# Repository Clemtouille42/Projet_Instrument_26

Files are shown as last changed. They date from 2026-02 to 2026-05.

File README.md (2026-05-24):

#  Projet Instrument : Harpe Sans Contact

##  Présentation générale
Ce projet consiste à concevoir et réaliser une harpe électronique sans cordes physiques, dans laquelle les cordes traditionnelles sont remplacées par des faisceaux de détection. Lorsqu'un utilisateur est détecté par le capteur, la harpe analyse la position et la hauteur de la main pour émettre une note de musique spécifique. Ce système reproduit le principe de jeu d'une harpe classique tout en exploitant des technologies modernes de détection et de traitement du signal.

##  Objectifs du projet
* Mettre en œuvre une détection spatiale précise à l'aide d'un capteur multizone.
* Concevoir une carte électronique sur mesure intégrant la gestion d'alimentation et le traitement.
* Traiter les données de distance en temps réel pour les transformer en notes musicales.
* Restituer un signal sonore propre correspondant à la note calculée.

---

##  Architecture du système

Notre architecture repose sur trois grands piliers matériels, de la détection à la restitution sonore, en passant par une gestion rigoureuse de l'énergie.

### 1. Détection des mouvements
* **Capteur Time-of-Flight (ToF) :** VL53L8CX, utilisé pour déterminer avec précision la distance et la position de la main dans l'espace.
* **Adaptation et Communication :** Communication via le bus I2C avec des résistances de Pull-up (4.7 kΩ) sur les lignes SDA/SCL. Un adaptateur de niveaux est prévu pour assurer la compatibilité des signaux entre le capteur et le microcontrôleur.
* **Connectique :** Connecteurs dédiés pour lier physiquement le module capteur à la carte de traitement principale.

### 2. Traitement et Gestion de l'Énergie
* **Microcontrôleur :** STM32G431KB. Il est le cerveau du système : il reçoit les données de position du capteur via I2C et les convertit mathématiquement en notes (ex: mapping de plages de distances vers DO, RE, MI...).
* **Gestion de l'alimentation :** * **Alimentation directe en 5V** via le connecteur USB-C.
  * **Résistances CC (5.1 kΩ) :** Tirées vers la masse (GND) sur les broches CC1 et CC2 pour la négociation de puissance et assurer que le système reçoit bien ses 5V.
  * **LDO (Régulateur de tension) :** Abaisse le 5V en une tension stable de 3.3V, indispensable pour alimenter le microcontrôleur et le capteur ToF.
  * **Filtrage et découplage :** Utilisation de billes de ferrite et de condensateurs de découplage pour garantir une tension propre, sans parasites, afin de ne pas perturber les communications I2C et les traitements internes.

### 3. Restitution du signal
* **Isolation :** Optocoupleur pour garantir l'isolation électrique, protéger le microcontrôleur et éliminer les boucles de masse.
* **Audio :** Le signal est traité par un amplificateur avant d'être envoyé au mini haut-parleur pour la vibration sonore finale.
* **Interface externe :** Prise / Câble MIDI permettant une sortie numérique vers d'autres instruments ou un ordinateur.

---

##  Logiciel Embarqué (Work In Progress)

Le firmware (dossier `/CODE`) est actuellement en cours de développement et de débogage.

* **Communication :** Interfaçage I2C en cours d'implémentation pour récupérer la matrice de données du VL53L8CX.
* **Algorithme prévu :** Découpage du champ de vision du capteur en plusieurs zones virtuelles. Chaque zone correspond à une "corde". La distance mesurée dans une zone détermine la hauteur de la note (Grave/Aiguë) tandis que la zone elle-même détermine la note de la gamme.

---

##  Structure du dépôt

L'arborescence du projet est organisée de la manière suivante :

* 📁 **`Armature harpe/`** : Fichiers liés à la structure mécanique de la harpe (bois, impression 3D).
* 📁 **`CODE/`** : Code source C pour le microcontrôleur STM32 (En cours de développement).
* 📁 **`Commandes/`** : Contien les resource concernant la conception du pcb.
* 📁 **`Composants/`** : Regroupe toutes les ressources matérielles brutes (Datasheets des composants, empreintes spécifiques, nomenclature complète `composants.xlsx`).
* 📁 **`KiCad Harpe/`** : Projet KiCad complet incluant les schémas électroniques et le routage du PCB de notre carte sur mesure.
Pour plus de détaille lire les readme des sous parties.
---

##  L'Équipe

Projet réalisé dans le cadre de notre 1ère année de cycle ingénieur (ENSEA) par :

* **Clément SERVAES** - Le Grand Manitou
* **Damien GANTCHEV** - Le Grand Vizir
* **Serge AROU** - Le Grand Chanteur
* **Maxime LEBRUN** - Le Grand Brun

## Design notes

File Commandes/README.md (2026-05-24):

# Conception du PCB et choix des composants

Ce readme va aborder la partie conception du pcb et choix des composants en détail. Je vais le faire pour chaque partie que l'on peut voir sur le schematics, donc je vous invite à le regarder.

---

## Régulateur / alimentation

Cette partie est composée de deux régulateurs de tension en série qui régulent successivement le 5V puis le 3.3V pour délivrer du 1.8V et 3.3V. La source d'alimentation principale pour la carte est le 5V de l'USB.

### Choix des composants

* **Le BU33SD5WG-TR :** C'est un régulateur qui sort du 3.3V. Celui-ci sert à alimenter les composants fonctionnant en 3.3V avec le 5V de l'usb. C'est un composant plutôt standard pour ce genre de tâche.

* **AP2112K-1.8 :** C'est aussi un régulateur, sauf que celui-ci sort du 1.8V. Le choix de ce composant est plus stratégique car il sort sur IOvdd qui est extrêmement important pour le lidar (qui est alimenté en 3.3v et 1.8v). J'ai choisi ce composant car il ne laisse pas passer de bruit, possède un bon taux de réjection et le courant fourni correspond à la consommation.

---

## Conception
La principale contrainte de cette architecture réside dans l'alimentation en 1,8 V des lignes d'entrées/sorties (E/S) du microcontrôleur STM32. L'objectif initial était d'intégrer des adaptateurs de niveau logique (*level shifters*) afin d'éviter une sous-alimentation du STM32 mais cette option a été écarté pour simplifier la conception du pcb (réduire le nombre de composants). 

Cette configuration a imposé des contraintes d'interfaçage, la plupart des autres composants du PCB utilisant une tension IOVDD standard à 3,3 V. Cela a généré des conflits de compatibilité, notamment :
* L'interface de programmation ST-Link, qui opère nativement avec des niveaux logiques de 3,3 V.
* L'interface de débogage SWD, qui s'est retrouvée privée de sa tension de référence IOVDD.
---

## Voie d'amélioration

Les régulateurs ont une pin on/off (enable) qui permet de les désactiver ou activer. Sauf que j'ai routé la pin vers le STM32 afin de pouvoir séparer le 5V en cas de problème ou autre. 

Le fait est que l'USB étant, lors de la phase de test, la seule source d'alimentation puisque IOVDD n'est pas branchée (car les cartes en SWD pull up la tension à 3.3V), la carte s'est retrouvée sans alimentation. Un pont entre EN et le 5V suffit à corriger ce problème.

## Capteur de mouvement / LiDAR

Cette section aborde la partie capteur de la carte, utilisée pour concevoir les cordes virtuelles et sans contact de la harpe.

* **Le VL53L8CX :** Il s'agit d'un module LiDAR d'état solide multizone. Il mesure les distances sur un FoV (champ de vision) de 65° sous forme de matrice 4x4 ou 8x8. Le composant intègre son propre microprocesseur pour traiter le signal en interne. Il est capable de détecter plusieurs cibles au sein d'une même zone (par exemple, à travers une vitre), offre une immunité face au bruit optique et intègre un algorithme de détection de mouvement.

Le composant est multi-tension : il doit être alimenté en 3,3 V (maximum 3,6 V) pour sa partie analogique/laser, et en 1,8 V pour ses IOVDD.

---

## Conception

Le choix de ce composant repose sur sa capacité à mesurer plusieurs zones simultanément, répondant ainsi à l'exigence du cahier des charges de gérer plusieurs cordes. L'utilisation d'un capteur unique permet de limiter la taille et la complexité du PCB ; en effet, multiplier les LiDARs individuels en $I^2C$ aurait grandement complexifié la gestion des adresses.

Bien que le traitement embarqué du signal soit un aspect secondaire pour notre application, il offre l'avantage de pouvoir intégrer une vitre de protection transparente sur la harpe. De plus, la précision est excellente et le composant intègre son propre système d'auto-calibration.

---

## Axes d'amélioration

L'intégration logicielle de ce composant s'avère complexe. Comme mentionné précédemment, il possède son propre microcontrôleur et nécessite le chargement d'un firmware propriétaire au démarrage, sans quoi aucune mesure n'est possible. 

Ce firmware pèse environ **80 Ko**. Rapporté aux **128 Ko** de mémoire Flash disponibles sur notre STM32G431KBT6, cela représente une charge considérable, d'autant plus qu'il faut conserver de l'espace pour les fonctions HAL, la pile logicielle et le reste de l'application.

---

## Solutions correctives

Pour pallier ce problème de mémoire, deux pistes sont envisageables :
1. **Migration matérielle :** Remplacer le microcontrôleur actuel par un modèle doté d'une mémoire Flash plus importante (par exemple, un STM32 avec 256 Ko ou 512 Ko de Flash) ne pas prendre les composant que l'on nous demande de mettre car dans les stock.
2. **Optimisation logicielle :** Optimiser l'empreinte mémoire du code global et ajuster les options de compilation (par exemple, via le flag d'optimisation de taille `-Os` sous GCC) pour réduire la taille des bibliothèques HAL et du code utilisateur.

## Interface USB-C

L'intégration d'un port USB Type-C sur la carte est un choix d'ergonomie, permettant d'alimenter le système en 5 V de manière universelle. Néanmoins, nous avons configuré le STM32 pour qu'il puisse transmettre et recevoir des données via cette interface, offrant ainsi plus de polyvalence pour les phases de test et de débogage.

---

## Conception et routage

Le port USB-C utilise un routage standard incluant les lignes de données ($D+/D-$), le bus d'alimentation ($V_{BUS}$ / 5 V) et la masse ($GND$). L'ensemble a été routé de manière symétrique pour garantir la réversibilité native du connecteur mâle.

Il y a un USBLC6-2SC6 qui sert de protection pour le port usb c'est un composant standard qui est en stock a l'école.

Cependant, deux contraintes critiques liées à la haute vitesse et à la conception du PCB sont à noter :
* **Paires différentielles :** Les lignes $D+$ et $D-$ forment une paire différentielle qui exige une adaptation d'impédance et des longueurs de pistes strictement identiques (skews minimisés). Bien que cette condition soit globalement respectée sur notre routage, l'équilibrage des longueurs peut encore être affiné.
* **Intégrité du signal :** La présence de vias sur ces lignes de données n'est pas optimale et peut introduire des discontinuités d'impédance.

---

## Axes d'amélioration

Lors de la phase de conception, un problème de synchronisation sous KiCad a empêché le transfert correct des informations de routage depuis le schéma vers le layout (footprint). À cause de ce bug, la ligne 5 V ($V_{BUS}$) n'a pas été reliée au régulateur de tension 3,3 V.

De plus, le routage de la paire différentielle USB pourra être optimisé dans une future révision de la carte en supprimant complètement les vias et en appliquant un *length-matching* parfait.

Effectuer des test pour étudier l'adaptation d'impédence.

---

## Solution corrective

Pour valider le prototype fonctionnel malgré l'erreur de routage du $V_{BUS}$, un strap (pont filaire) a été soudé manuellement pour amener directement le 5 V aux bornes du régulateur de tension.

## Interface midi

L'interface midi est indiquer dans le cahier des charges, elle permet de communiquer a l'ordinateur les notes jouer par l'instrument.

* **Le ACPL-M61L:** Il s'agit d'un opto-coupleur il est obligatoir d'apres les specs du midi , cela permet d'éviter les boucles de masse.
* * **Le le 74LVC1G125:** Il s'agit du buffer qui permet a la communiaction UART qui sort de l'opto-coupleur d'avoir assez de puissance pour etre reçus de maniere correcte coté PC.

---

## Conception

Je vais etre bref sur cette partie car le Midi est pas ma partie du projet. J'ai choisis les composant standard proposer par des forums sur l'audio.Le APCL respecte le baud rate du midi et la ferite permet d'éviter certain parasite et d'augmenter la portée du midi. Nous avons choisis de faire un midi in/out pour tester la conception entiere d'une interface midi. 

---

## Axes d'amélioration

Je n'ai pas commander la ferite, ça impacte pas vraiment les resultat car le cable commander (voir liste des composants) est court <1m. 
nous avons pas pu tester pleinment la communication par manque de temps.

---

## Solutions correctives

Pousser des test de CEM pour étudier l'utilitée de la ferrite.

## Partie Audio

Afin de rendre la harpe autonome et de ne pas la faire dépendre entièrement de l'interface MIDI et d'un ordinateur externe, un étage d'amplification de puissance et un haut-parleur (speaker) ont été intégrés directement sur la carte.

* **Le PAM8403 :** Il s'agit d'un amplificateur audio stéréo de classe D. Très populaire dans les systèmes embarqués pour son excellent rendement énergétique, il permet de piloter directement de petits haut-parleurs sans nécessiter de dissipateur thermique externe.

---

## Conception

Le haut parleur indique dans sa documentation qu'il faut de la férite sur ses deux entrée donc nous avons commander celle-ci. 
---

## Axes d'amélioration

Nous avons pas eu le temps de tester cette partie en profondeur donc c'est compliquer d'avoir un retour d'expériences mais j'imagine que des teste sur l'adaptation d'impédence ou autres aurais pus etre utiles.

néamoins le haut parleur arrive a sortir des bip boup en testant les sortie DAC.

---

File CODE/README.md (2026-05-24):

# Compte-Rendu de Projet : Partie Développement et Programmation

Ici se trouve la partie logicielle du projet. Cela comprend :

* Programme brut
* Description de l’avancée du projet et des objectifs

## 1. Choix de l'Architecture Matérielle et Programmation

Pour la programmation de notre microcontrôleur cible, un **STM32G431KBT6**, on a choisi de le codé en passant par une liaison **SWD (Serial Wire Debug)**. Cette méthode permet d'alléger le design de notre carte finale en évitant d'y intégrer un programmateur lourd.

Pour réaliser cette interface, nous avons utilisé une carte **NUCLEO** configurée en programmateur externe :
* **Configuration de la Nucleo :** Nous avons **retiré les cavaliers (jumpers)** du connecteur ST-LINK afin d'isoler le programmateur embarqué du microcontrôleur de la Nucleo.
* **Connection SWD :** Nous avons ensuite connecté les broches SWCLK, SWDIO, NRST et la masse (GND) du ST-LINK directement sur les broches correspondantes de notre processeur cible pour y injecter le code.

---

## 2. Tests de Validation et Communication I2C

Une fois la chaîne de programmation validée, nous avons développé un premier programme de test pour vérifier le bon câblage et la communication avec notre environnement matériel, plus précisément via le bus **I2C**.

### Scan du bus I2C :
Nous avons implémenté un code de balayage (*I2C scanner*) dont le but est de tester toutes les adresses esclaves possibles sur le bus.
* **Résultat :** Le programme de scan a détecté et retourné l'adresse décimale **41**.
* **Validation :** En confrontant ce résultat avec la documentation technique de notre capteur, nous avons confirmé que l'adresse **0x29** est bien celle par défaut du composant. Cela valide le bon fonctionnement de notre code de communication et l'intégrité matérielle de la liaison I2C.

---

## 3. Limitations Mémoire et Problématiques Rencontrées

L'étape suivante consistait à intégrer les drivers officiels (API Ultra Lite Driver - ULD) d'STMicroelectronics pour exploiter le capteur de vol (ToF) **VL53L8CX** et récupérer sa matrice de données. 

C'est à ce stade que nous avons rencontré une limitation technique majeure liée au dimensionnement du microcontrôleur :

> ⚠️ **Saturation de la mémoire :**
> Le **STM32G431KBT6** dispose d'une configuration mémoire trop restreinte pour cette application (32 Ko de RAM et 128 Ko de mémoire Flash). Les drivers nécessaires à l'initialisation et à la gestion des matrices du VL53L8CX requièrent un volume de mémoire Flash et de RAM supérieur à ce que notre processeur peut embarquer. 

Le code étant trop lourd, il a été impossible de compiler et de téléverser l'application complète. Nous n'avons donc pas pu finaliser la récupération de la matrice de données.

---

## 4. Conclusion et Perspectives

Ce projet a permis de valider avec succès notre stratégie de programmation par liaison SWD ainsi que la communication I2C avec le capteur. Cependant, le manque de mémoire (Flash/RAM) du processeur choisi s'est révélé être un facteur bloquant pour l'utilisation des drivers du VL53L8CX.

Pour finaliser ce projet, il aurait été nécessaire de :
1. **Migrer vers un microcontrôleur plus performant** de la même famille mais disposant de plus de mémoire (Flash et RAM).
2. **Développer un driver personnalisé ultra-léger**, en faisant l'impasse sur l'API officielle pour ne coder que les registres strictement nécessaires, bien que cette solution soit beaucoup plus complexe à mettre en œuvre.

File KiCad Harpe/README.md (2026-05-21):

Ce fichier contient les schémas et le PCB réalisés sur KiCad, ainsi que les fichiers Gerber utilisés pour la commande du PCB chez JLCPCB.

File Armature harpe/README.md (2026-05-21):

Damiens met tes fichier içi et modifie le readme pour expliquer ta conception de l'armature .

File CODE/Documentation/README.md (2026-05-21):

Documentation diverse svp lire avant de faire un code.

ne pas brancher OIVDD!!!

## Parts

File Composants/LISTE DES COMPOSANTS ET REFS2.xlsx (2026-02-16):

Composant | Type | Quantité | Référence | Commentaire
Mini haut-parleur | Haut-parleur miniature en boîtier 3W 4Ohm avec JST XH2.54 | 2 | https://uk.rs-online.com/web/p/speaker-drivers/1812071 | parfaitement compatible PAM8403
Prise USB | USB_C_Receptacle_USB2.0_16P | 2 | https://eu.mouser.com/ProductDetail/Hirose-Connector/CX90B-16P1?qs=wT7LY0lnAe2kWx47ZtJoeg%3D%3D | Pour USB 2.0, il faut résistances CC1 / CC2 = 5.1 kΩ vers GND (sinon pas d’alim) Si c’est uniquement pour l’alimentation, pas besoin de lignes D+ / D− condensateurs de découplage proches (100 nF + 1 µF) à ajouter ?
Câble MIDI | Thomann Midi USB | 2 | https://www.thomann.fr/swissonic_midiconnect_2.htm | Broche 4 -> courant via résistance Broche 5 -> signal Broche 2 -> masse (souvent reliée au blindage)
Capteur de mouvement | VL53L8CX | 2 | https://www.mouser.fr/ProductDetail/STMicroelectronics/VL53L8CXV0GC-1?qs=T%252BzbugeAwjhc9idkQC%252BF8g%3D%3D | Capteur ToF 8×8 zones I²C À prévoir : Pull-ups I²C (souvent 2.2k–4.7kΩ vers 3.3V) Bien vérifier : tension logique 3.3V uniquement adresse I²C configurable si plusieurs capteurs
Microcontrôleur | STM32G431KB | 2 | https://www.mouser.fr/ProductDetail/STMicroelectronics/NUCLEO-G431KB?qs=T3oQrply3y8wb4tYAWO69g%3D%3D | Points à ne pas oublier : Programmation/debug : Connecteur SWD (SWDIO, SWCLK, GND, 3V3) Sonde ST-Link Condos de découplage : 100 nF par pin VDD 1–4.7 µF en bulk
Amplificateur | classe D type PAM8403 | 2 | https://www.mouser.fr/ProductDetail/Diodes-Incorporated/PAM8403DR-H?qs=%252BSlWJf1dfkKg75OIzZ5AmQ%3D%3D | Entrée audio : nécessite un signal analogique -> DAC interne STM32 ou PWM filtré Filtrage sortie : Le PAM8403 est classe D → traces courtes Ferrites / LC conseillés si PCB propre
Transformateur | BU33SD5WG-TR | 2 | https://www.mouser.fr/ProductDetail/ROHM-Semiconductor/BU33SD5WG-TR?qs=%2FKR40Cd6GUrQDzRkUEt69Q%3D%3D | Condos (respect datasheet, mais en pratique) : IN: 1 µF + 100 nF OUT: 1 µF (ou 2.2–4.7 µF) + 100 nF Découplage MCU : 1× 100 nF par VDD (0603 X7R) 1× 4.7 µF “bulk” proche MCU Réfs simples: Murata GRM188R71C104KA01 (100nF), GRM188R60J475KE19 (4.7µF)
Ferrite | 600ohm 100Mhz | 2 | https://www.mouser.fr/ProductDetail/Fair-Rite/2944666651 | Très bien pour : Alim USB Entrée ampli audio Réduction EMI
LDO Régulateur de tension | AP2112K-1.8 TGR1 | 2 | https://www.mouser.fr/ProductDetail/Diodes-Incorporated/AP2112K-1.8TRG1?qs=x6A8l6qLYDBx1xhw8AX2cw%3D%3D | Fabrican diodes , voir montage recomandé il y a des spé au niveaux des condensateur .
adapateur de niveaux |  | 2 | https://www.mouser.fr/ProductDetail/Texas-Instruments/PCA9306DCUR?qs=wgAEGBTxy7nQr5PRxNBUNA%3D%3D
Prise MIDI | RS Stock | 2 | 490-923 | Il faut aussi : Optocoupleur (OBLIGATOIRE côté entrée MIDI) -> 6N138, 6N137 ou PC900 Résistances MIDI : 220 Ω et 470 Ω Diode (1N4148) ?
2× résistances CC (Rd) : 5.1 kΩ ±1% (0603/0805) vers GND sur CC1 & CC2 | Yageo RC0603FR-075K1L | 2 | https://www.mouser.fr/ProductDetail/YAGEO/RC0603FR-075K1L?qs=gt6vzsuosg2jUUwxnI2PJQ%3D%3D
Pull-up SDA/SCL : 2.2 kΩ à 4.7 kΩ vers 3.3 V (0603) Safe default: 4.7 kΩ (si bus pas trop long) | Yageo RC0603FR-074K7L | 2 | https://www.mouser.fr/ProductDetail/YAGEO/RC0603FR-074K7L?qs=gt6vzsuosg37y0l7Vt36bQ%3D%3D
Connecteur | TE Connectivity FASTIN-FASTON .250 Black Uninsulated Female Spade Connector, Crimp, 6.35 x 0.81 mm Tab Size 18 AWG to 14 | 4 | https://uk.rs-online.com/web/p/spade-connectors/2451703?msockid=3fead525910169961f7cc37b905468a3
Optocoupleur | Vishay 6N137, Broadcom/Avago HCPL-2631 | 2 | https://www.mouser.fr/ProductDetail/Vishay-Semiconductors/6N137?qs=xCMk%252BIHWTZMrQz4FyDXhMg%3D%3D
Passifs | 2× 220 Ω (limitation courant côté DIN) : Yageo RC0603FR-07220RL 1× 10 kΩ pull-up côté sortie opto : Yageo RC0603FR-0710KL 1× 1N4148 (protection / clamp selon schéma) : 1N4148W (SMD) ou 1N4148 (THT) 1× 470 Ω : Yageo RC0603FR-07470RL | 2

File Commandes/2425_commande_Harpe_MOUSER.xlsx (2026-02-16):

MOUSER |  |  |  |  | Envoyez un seul fichier par mail!
Pos | I | P | Art | Désignation | Qté commandée | UA | Date Livraison | Prix unitaire | Devise | Q | Grpe | Div
10 | Z |  |  | Capteur de mouvement : VL53L8CX 400 cm 1.2 V 3.3 V 16 LGA16 optique / ref : 511-VL53L8CXV0GC/1 | 2 | PC | 23.02.2026 | 5.93 | EUR | PC | TA.01
20 | Z |  |  | Microcontrôleur : Carte de développement / ref : 511-NUCLEO-G431KB | 2 | PC | 23.02.2026 | 10.93 | EUR | PC | TA.01
30 | Z |  |  | Amplificateur audio / ref : 621-PAM8403DR-H | 2 | PC | 23.02.2026 | 0.60 | EUR | PC | TA.01
40 | Z |  |  | Régulateur de tension BU33SD5WG-TR, 500mA, SSOP, 5 broches / ref : 755-BU33SD5WG-TR | 2 | PC | 23.02.2026 | 0.38 | EUR | PC | TA.01
50 | Z |  |  | Perle ferrite / ref : 623-2944666651 | 2 | PC | 23.02.2026 | 0.34 | EUR | PC | TA.01
60 | Z |  |  | LDO Régulateur de tension ref : 621-AP2112K-1.8TRG1 | 2 | PC | 23.02.2026 | 0.19 | EUR | PC | TA.01
70 | Z |  |  | adapateur de niveaux ref :595-SNAHCT1G125DBVR | 2 | PC | 23.02.2026 | 0.12 | EUR | PC | TA.01
80 | Z |  |  | Octocoupleur ref : ACPL-M50L-000E | 2 | PC | 23.02.2026 | 1.93 | EUR | PC | TA.01
 |  |  |  | Frait de livraison : 20 € ( Livraison gratuite pour la plupart des commandes supérieures à 50 € (EUR))
MODE d'EMPLOI et CODE erreurs Version 19
1: indiquez le fournisseur ligne 1
2:remplissez pour chaque ligne commandée les 4 champs en rouge selon les règles suivantes:
 | Art
 |  |  | 2.1 | Ne mettez rien ici tout comme dans P: remplissez les zones rouges (et pas ailleurs)
 | Désignation
 |  |  | 2.2 | Ne dépassez pas les 40 caractères: il seront automatiquement effacés lors de la recopie
 |  |  | 2.3 | Mettre une courte descritption suiivi du code commande du fournisseur
 |  |  | 2.4 | Pour RS et Farnell : mettre le code commande RS ou Farnell (7 à 9 chiffres) (et pas la référence constructeur) après la courte description
 |  |  | 2.5 | Exemple: Condensateur 1uF 0805 125-4857
 | Qté commandée
 |  |  | 2.6 | C'est le nombre d'unités correspondant au prix unitaire
 |  |  | 2.7 | Attention il y a des pièges
 |  |  | 2.8 | avec RS par exemple on vous demande parfois de commander par lot de 5 par exemple
 |  |  | 2.9 | si vous commandez 1 lot : le nombre d'unité est alors 5 pour 1 lot et non 1
 | date
 |  |  | 2.10 | Pour la date: mettre la de date dans une semaine
 |  |  | 2.11 | La mettre au format JJ.MM.AAAA
 |  |  | 2.13 | Bien utiliser les points comme séparateur
 | prix unitaire
 |  |  | 2.14 | Le prix est le prix HT (sans la TVA 20%) en euros d'une unité
 |  |  | 2.15 | arrondi au centime supérieur (0.012 euros devient 0.02!)
 |  |  | 2.16 | avec pour séparateur le point
 |  |  | 2.17 | n'utilisez pas le symbole euros d'excel
3: frais de port
 |  |  | 3.1 | ajoutez une ligne pour les frais de port
 |  |  | 3.2 | dont la désignation est "frais de port"
 |  |  | 3.3 | pas de frais de port à mettre pour RS ou Farnell
 |  |  | 3.4 | Renseignez vous pour connaître les frais de port
4: conseils complémentaires
 |  |  | 4.1 | Ne modifier que les 4 champs en rouge
 |  |  | 4.2 | Ne pas modifier le document sinon cela n'a plus aucun intérêt
 |  |  | 4.3 | Mettez les références dans le même ordre que celui de la commande
 |  |  | 4.4 | Vérifier bien sur les sites les références et les prix!
 |  |  | 4.5 | N'oubliez pas les frais de port!: ajoutez une ligne pour les mentionner
5: sauvegardez le fichier au format xls

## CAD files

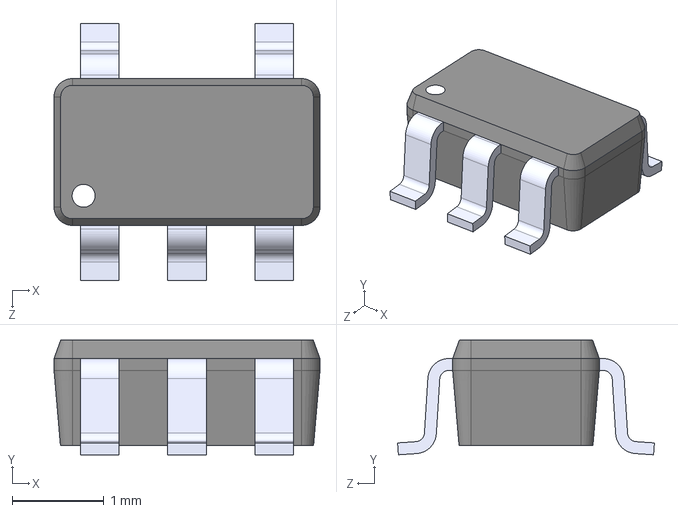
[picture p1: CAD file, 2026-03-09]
Composants/Empreinte Composant/BU33SD5WG-TR/BU33SD5WG-TR.step
2.90 x 1.25 x 2.80 mm

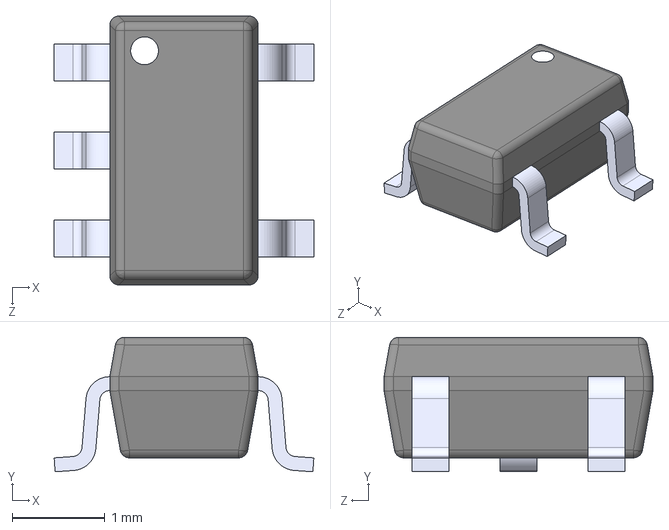
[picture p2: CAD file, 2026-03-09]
Composants/Empreinte Composant/SN74AHCT1G125DBVR/SN74AHCT1G125DBVR.step
2.80 x 1.45 x 2.90 mm

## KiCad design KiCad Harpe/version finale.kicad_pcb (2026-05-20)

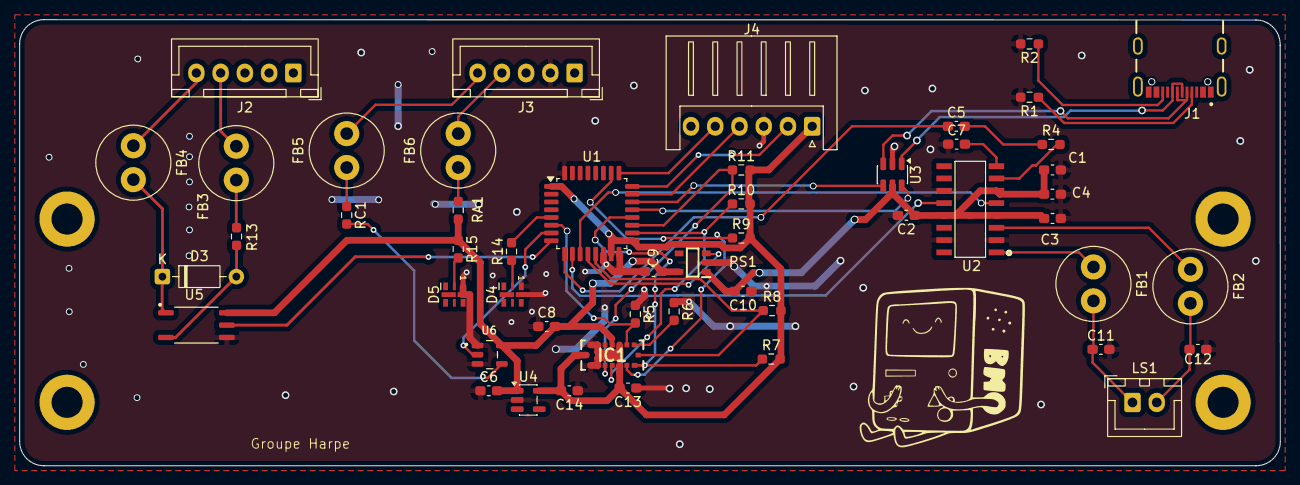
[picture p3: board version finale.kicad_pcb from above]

Board: 2 copper layers, 130.0 x 46.0 mm, 51 parts (0 on the bottom side), 46 nets.

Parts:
C1: 470uF; C_0603_1608Metric_Pad1.08x0.95mm_HandSolder
C2, C3, C4, C6, C7, C9, C10, C14: 1uF; C_0603_1608Metric_Pad1.08x0.95mm_HandSolder
C5: 0.47uF; C_0603_1608Metric_Pad1.08x0.95mm_HandSolder
C8: 4,7uF; C_0603_1608Metric_Pad1.08x0.95mm_HandSolder
C11, C12: 220pF; C_0603_1608Metric_Pad1.08x0.95mm_HandSolder
C13: 100nF; C_0603_1608Metric_Pad1.08x0.95mm_HandSolder
D3: 1N914; D_DO-35_SOD27_P7.62mm_Horizontal
D4, D5: LED; LED-APA102-2020
FB1, FB2: 300 Ohm / 100MHz; L_Radial_D7.5mm_P3.50mm_Fastron_07P
FB3, FB4, FB5, FB6: 1K@100MHz; L_Radial_D7.5mm_P3.50mm_Fastron_07P
IC1: VL53L8CXV9GC_1
J1: USB_C_Receptacle_USB2.0_16P; GCT_USB4105-GF-A
J2, J3: Conn_01x05_Pin; JST_XH_B5B-XH-A_1x05_P2.50mm_Vertical
J4: Conn_01x06_Pin; JST_XH_S6B-XH-A_1x06_P2.50mm_Horizontal
LS1: Speaker; JST_XH_B2B-XH-A_1x02_P2.50mm_Vertical
PS1: BU33SD5WG-TR
R1, R2: 5,1k; R_0603_1608Metric_Pad0.98x0.95mm_HandSolder
R4: 18k; R_0603_1608Metric_Pad0.98x0.95mm_HandSolder
R5, R6, R7, R8, R9: 47k; R_0603_1608Metric_Pad0.98x0.95mm_HandSolder
R10, R11: 2.2k; R_0603_1608Metric_Pad0.98x0.95mm_HandSolder
R13: 220; R_0603_1608Metric_Pad0.98x0.95mm_HandSolder
R14, R15: 1k; R_0603_1608Metric_Pad0.98x0.95mm_HandSolder
RA1: 33; R_0603_1608Metric_Pad0.98x0.95mm_HandSolder
RC1: 10; R_0603_1608Metric_Pad0.98x0.95mm_HandSolder
U1: STM32G431KBTx; LQFP-32_7x7mm_P0.8mm
U2: PAM8403DR
U3: USBLC6-2SC6; SOT-23-6
U4: AP2112K-1.8; SOT-23-5
U5: ACPL-M61L-000E; ACPL-M50L-000E
U6: 74LVC1G125; SN74AHCT1G125DBVR

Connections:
+3.3V: C6.2, C8.2, C9.2, IC1.C4 (AVDD), PS1.5 (VOUT), R15.1, RA1.2, U4.1 (VIN), U5.6 (VDD), U6.5 (VCC)
+5V: C1.1, C2.1, C3.1, C4.2, C10.2, PS1.1 (VIN), U2.4 (PVDD@1), U2.6 (VDD), U2.13 (PVDD@2), U3.5 (VBUS)
+OUT_L: FB1.1, U2.1 (+OUT_L)
-OUT_L: FB2.1, U2.3 (-OUT_L)
ANODE: D3.1 (K), FB4.2, U5.1 (ANODE)
CATHODE: D3.2 (A), R13.2, U5.3 (CATHODE)
Data_N1: J1.A6 (D+), J1.B6 (D+), U3.1 (I/O1)
Data_N2: U1.21 (PA11), U3.6 (I/O1)
Data_P1: J1.A7 (D-), J1.B7 (D-), U3.3 (I/O2)
Data_P2: U1.22 (PA12), U3.4 (I/O2)
GND: C1.2, C2.2, C3.2, C4.1, C6.1, C7.1, C8.1, C9.1, C10.1, C11.2, C12.1, C13.1, C14.1, D4.1 (K), D5.1 (K), IC1.A6 (RSVD1), IC1.A7 (RSVD2), IC1.B4 (GROUND_1), IC1.C3 (GND), IC1.C6 (RSVD3), IC1.C7 (GROUND_2), J3.2, J4.3, PS1.2 (GND), R1.2, R2.2, R5.1, R6.1, U1.14 (VSSA), U1.16 (VSS), U1.32 (VSS), U2.2 (PGND@1), U2.11 (GND), U2.15 (PGND@2), U3.2 (GND), U4.2 (GND), U5.4 (GND), U6.1, U6.3 (GND)
INL: C5.1, U1.9 (PA4)
INT: IC1.A1 (INT), R7.1, U1.20 (PA10)
IOVDD: C13.2, C14.2, IC1.A3 (IOVDD), IC1.B7 (CORE_1V8), J4.1, R7.2, R8.2, R9.2, R10.2, R11.2, U1.1 (VDD), U1.15 (VDDA), U1.17 (VDD), U4.5 (VOUT)
LPn_EN_COM: IC1.A2 (LPN), R9.1, U1.26 (PB3)
MUTE: U1.11 (PA6), U2.5 (MUTE)
NCS: IC1.C2 (NCS), R5.2, U1.6 (PA1)
unnamed: C5.2, R4.1
unnamed: C11.1, FB1.2, LS1.1
unnamed: C12.2, FB2.2, LS1.2
unnamed: D4.2 (A), R14.1
unnamed: D5.2 (A), R15.2
unnamed: FB3.1, R13.1
unnamed: FB5.1, RC1.1
unnamed: FB6.1, RA1.1
unnamed: IC1.C1 (SPI_I2C_N), R6.2
unnamed: J1.A5 (CC1), R1.1
unnamed: J1.B5 (CC2), R2.1
unnamed: FB3.2, J2.4
unnamed: FB4.1, J2.5
unnamed: FB6.2, J3.4
unnamed: FB5.2, J3.5
unnamed: R4.2, U2.7 (INL)
unnamed: C7.2, U2.8 (VREF)
RC: RC1.2, U6.4
SCL: IC1.A5 (SCL/MCLK), R11.1, U1.19 (PA9)
SDA: IC1.A4 (SDA_/_MOSI), R10.1, U1.18 (PA8)
SHDN: U1.10 (PA5), U2.12 (SHND)
STBY: PS1.3 (STBY), U1.12 (PA7)
SWDIO: J4.4, U1.23 (PA13)
SW_Reset: J4.5, U1.25 (PA15)
SYNC: IC1.B1 (SYNC), R8.1, U1.13 (PB0)
SYS_LED: R14.2, U1.5 (PA0)
UART RX: U1.8 (PA3), U5.5 (VO)
UART TX: U1.7 (PA2), U6.2
WSCLK: J4.2, U1.24 (PA14)

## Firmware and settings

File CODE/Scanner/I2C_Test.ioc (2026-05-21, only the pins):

Mcu.UserName=STM32G431KBTx
PA13.Signal=SYS_JTMS-SWDIO
PA14.Signal=SYS_JTCK-SWCLK
PA8.Signal=I2C2_SDA
PA9.Signal=I2C2_SCL

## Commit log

2026-02-02 Create Hardware
    Tout ce qui concerne les composants / PCB
2026-02-02 Liste de composant
2026-02-02 Add Motion Sensor VL53L8CX to component list
2026-02-02 Add files via upload
    Lidar 2d
2026-02-02 Add STM32G431KB microcontroller to components list
2026-02-09 Update component list by removing entries
    Removed 'Haut Parleur' and 'Cable MIDI' entries from the component list.
2026-02-16 Rename composants (2).xlsx to composants.xlsx
    [composants.xlsx]
2026-05-11 Create PCB et Gerber
2026-05-12 Add files via upload
    Fichier drill + gerber pour la commande JLpcb
2026-05-21 Create CODE
    Ici se trouve la partie logicielle du projet. Cela comprend :
    * Programme brut
    * Description de l’avancée du projet et des objectifs
2026-05-21 Add files via upload
    SDK du Lidar
2026-05-21 Add files via upload
    le VLCX pour les nuls
2026-05-21 Revise README with updated project details and objectives
    Updated project description and objectives to reflect changes in sensor technology and system architecture.
2026-05-21 Create Capteur I2C
2026-05-24 Enhance README with project development details
    Added detailed project report covering development, programming choices, I2C communication tests, memory limitations, and future perspectives.
